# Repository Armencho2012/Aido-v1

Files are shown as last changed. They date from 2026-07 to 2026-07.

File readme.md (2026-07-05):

# AIDO — AI Study Assistant Robot

This repository contains the full AIDO project split across backend, frontend, firmware, tests, and 3D models.

## Repository structure

- `Aide server/` — backend voice API only, no browser UI.
- `Aide website/` — production-ready web application source and public assets.
- `Robot codes/` — MicroPython firmware and robot application logic.
- `Robot tests/` — hardware and software test scripts.
- `Robot 3d models/` — robot enclosure and part model files.

## Quick start

- Backend: run `Aide server` and configure `GROQ_API_KEY`.
- Frontend: build `Aide website` with `npm install` and `npm run build`.
- Robot firmware: deploy `Robot codes` to the Pico W device.
- Tests: run selected scripts from `Robot tests/harware` and `Robot tests/software`.

## Notes

- This repo is organized by subsystem, not by a single monolithic app.
- The backend service is API-only; the front-end and firmware are separate.
- Keep the `Aide website` folder clean from development-only artifacts.

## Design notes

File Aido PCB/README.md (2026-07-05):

# Aido PCB

This folder contains the printed circuit board design files for the AIDO project.

## Files

- `MyFirstController.kicad_sch` — schematic design
- `MyFirstController.kicad_pcb` — PCB layout
- `MyFirstController.kicad_prl` — PCB rules file
- `MyFirstController.kicad_pro` — PCB project file
- `ERC.rpt` — electrical rules check report
- `images/` — board diagrams and reference images

## Notes

- Use KiCad to open and edit the PCB design files.
- Keep generated artifacts out of source control if you want the repository clean.

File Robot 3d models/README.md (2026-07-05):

# Robot 3D Models

This folder contains the 3D model files for the AIDO robot design.

## Included files

- `Aido.stl` — main robot body for 3D printing or export
- `Aido.fbx` — main robot body for CAD, editing, or animation
- `back.stl` — secondary rear or cover part for printing
- `back.fbx` — secondary rear or cover part for CAD editing

## Usage

- Use `FBX` files for 3D modeling, editing, and visualization.
- Use `STL` files for 3D printing or slicing.
- Verify model units and orientation before exporting or printing.

## Notes

- Keep the `stl` and `fbx` files paired if you need both print-ready and editable versions.

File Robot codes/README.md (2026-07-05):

# Robot Codes

This folder contains the MicroPython firmware and application logic for the AIDO robot.

## Overview

The code is designed to run on the Pico W hardware and includes:

- `main.py` — primary application entry point
- `boot.py` — startup initialization and boot flow
- `config.py` — hardware pin assignments and configuration values
- `wifi.py` — WiFi connection manager
- `voice_client.py` — voice interaction client
- `tts_client.py` — text-to-speech client
- `mic.py`, `ssd1306.py`, `mpu6050.py`, `vl53l0x.py` — sensor and display drivers
- `flashcards.py`, `quiz.py`, `games.py`, `study_sync.py` — learning and interaction features

## Deployment

1. Copy the `Robot codes` files to the Pico W device storage.
2. Use Thonny, rshell, or a similar MicroPython tool.
3. Ensure `main.py` is present and the board boots from it.

## Notes

- Keep firmware code on the device and update only the required modules.
- Use the `config.py` file to verify pin assignments before hardware tests.

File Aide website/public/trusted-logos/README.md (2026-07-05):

# Trusted Logos

Current source of truth:

```bash
python3 scripts/fetch_trusted_logos.py
```

This downloads and writes:

- `logo-01.png`
- `logo-02.png`
- ...
- `logo-16.png`

If you want to split from a custom collage image instead, you can still use:

```bash
python3 scripts/extract_trusted_logos.py
```

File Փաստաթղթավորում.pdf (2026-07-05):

## ՎԱՆԱՁՈՐԻ ԹԻՎ 4 ՀԻՄՆԱԿԱՆ ԴՊՐՈՑԻ ԱՐՄԱԹ ՃԱՐՏԱՐԱԳԻՏԱԿԱՆ ԱՇԽԱՏԱՆՈՑ

# ՍԱՐՔԵՐԻ ԻՆՏԵԳՐՄԱՆ ՆԱԽԱԳԻԾ — ՏԵԽՆԻԿԱԿԱՆ ՓԱՍՏԱԹՈՒՂԹ

Խմբավար | Լուսինե Կոծինյան
Հեղինակ | Արմեն Ասլիկյան
Մասնակից | Մելս Մարտիրոսյան

Ի՞նչ է AIDO-ն

AIDO-ն խելացի ուսումնական օգնական է, այն միավորում է արհեստական բանականության մոդելները և ռոբոտաշինությունը՝ կրթական գործընթացն ավելի հետաքրքիր, արդյունավետ ու ինտերակտիվ դարձնելու համար: Այն հանդես է գալիս որպես անձնական թվային դասավանդող և օգնական: AIDO ն օգտագործում է ներկայիս լավագույն ԱԲ մոդելները հնարավորինս որակով պատասխան վերադարձնելու համար։

AIDO Study Assistant AI ռոբոտի հիմնական նպատակն է հեղափոխել ուսումնական գործընթացը՝ կապող օղակ հանդիսանալով առաջադեմ արհեստական բանականության և ֆիզիկական ռոբոտատեխնիկայի միջև: Ստեղծված լինելով որպես ինտերակտիվ և 24/7 հասանելի կրթական ընկեր՝ AIDO-ն նպատակ ունի հանրամատչելի դարձնել անհատականացված ուսուցումը՝ հարմարվելով յուրաքանչյուր սովորողի տեմպին ու ոճին: Ավտոմատացնելով ծավալուն ակադեմիական առաջադրանքները, ինչպիսիք են դասագրքերի վերլուծությունը, թիրախային թեստերի ստեղծումն ու բնական լեզվով ակնթարթային բացատրությունների տրամադրումը, ռոբոտը թեթևացնում է մտավոր ծանրաբեռնվածությունը և օպտիմալացնում սովորելու ժամանակը: Ի վերջո, AIDO-ն հանդես է գալիս ոչ թե պարզապես որպես պասիվ գործիք, այլ որպես նախաձեռնող կրթական գործընկեր, որը խթանում է նյութի խորը ընկալումը, բարելավում է գիտելիքների պահպանումը և բարձրորակ, տեխնոլոգիական մենթորությունը հասանելի է դարձնում

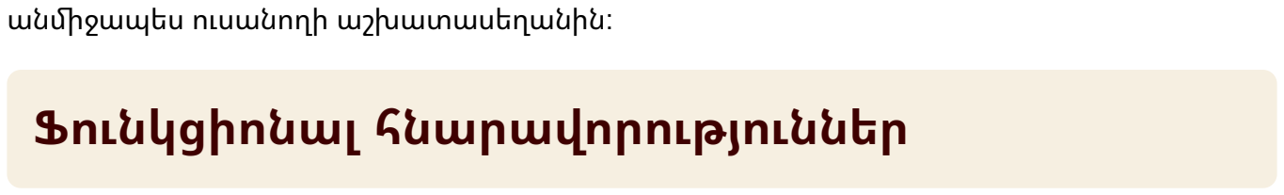
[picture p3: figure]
անմիջապես ուսանողի աշխատասեղանին:; Ֆունկցիոնալ հնարավորություններ

Ուսումնական նյութերի ավտոմատ ստեղծում․ Ռոբոտը ինքնաշխատ եղանակով գեներացնում է թեստեր (quizzes), հիշողության քարտեր (flashcards), վերլուծություններ (analyses) և ուսումնական քարտեզներ (study maps):

Խաղային էլեմենտներ (Gamification)․ Համակարգը ներառում է ներկառուցված կրթական խաղեր, որոնք ուսուցման գործընթացը դարձնում են ավելի հետաքրքիր:

Կարգավորումների բաժին (Settings)․ Օգտատերը կարող է հարմարեցնել ռոբոտի աշխատանքը և պարամետրերը հատուկ կառավարման վահանակի միջոցով:

Անիմացիաներ (Animations)․ Ռոբոտն ունի վիզուալ անիմացիաներ, որոնք ապահովում են կենդանի ու դինամիկ փոխազդեցություն սովորողի հետ:

Ինտերակտիվ երկխոսություն և դինամիկ թարմացում․ Օգտատերը կարող է խոսել ռոբոտի հետ, տալ հարցեր, իսկ ռոբոտը պատասխանում է դրանց: Զրույցի բովանդակության հիման վրա համակարգը ավտոմատ կերպով թարմացնում է թեստերը, ֆլեշ-քարտերը և մյուս ուսումնական նյութերը:

Վեբ տարբերակ (Web Version)․ Ռոբոտն ունի իր համապատասխան վեբ-կայքը, որն օգտատիրոջը հնարավորություն է տալիս կատարել ավելի ընդարձակ աշխատանքներ և

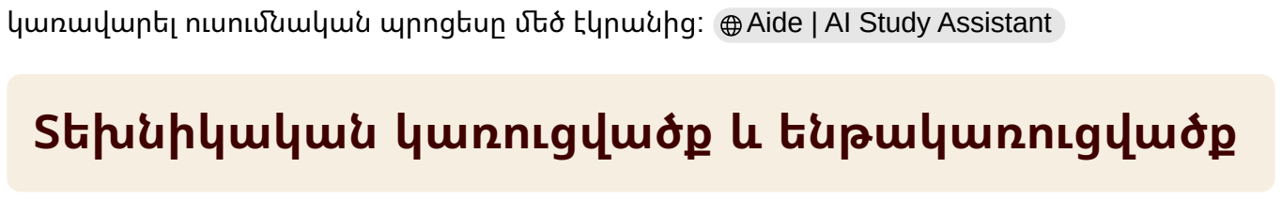
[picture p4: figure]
կառավարել ուսումնական պրոցեսը մեծ էկրանից:; Aide | AI Study Assistant; Տեխնիկական կառուցվածք և ենթակառուցվածք

Միկրոծրագրային ապահովում (Firmware)․ Ռոբոտի ներքին ծրագրային կոդը գրված է MicroPython լեզվով:

Վեբ տեխնոլոգիաներ (Web Stack)․ Նախագծի վեբ-կայքը մշակված է Node.js միջավայրում:

Սերվերային համակարգ (Hosting)․ Թե՛ ռոբոտի API սերվերները և թե՛ վեբ-կայքը հոսթինգ են անցնում Vercel հարթակում:

Տվյալների բազա (Database)․ Որպես կենտրոնական տվյալների բազա օգտագործվում է Supabase-ը, որը պահում է վեբ-կայքի և ռոբոտի ողջ տեղեկատվությունը:

Ձայնային հարցումների մշակման ալգորիթմ (Voice Processing Pipeline)

1. Ձայնագրում․ Ռոբոտը ձայնագրում է օգտատիրոջ հարցը և այն պահպանում որպես .wav ֆորմատի աուդիոֆայլ:
2. Աուդիոյի փոխանցում․ Ֆայլն ուղարկվում է Vercel-ում գտնվող սերվերներին:
3. Ձայնի տեքստայնացում (STT)․ Սերվերը ձայնային ֆայլը փոխանցում է Groq Cloud հարթակին, որտեղ whisper-large-v3-turbo մոդելի միջոցով աուդիոն վերածվում է տեքստի:
4. Պատասխանի գեներացում (LLM)․ Տեքստային հարցը մշակվում է llama-3.1-8b-instant մեծ լեզվական մոդելի կողմից, որն էլ պատրաստում է համապատասխան պատասխանը:
5. Տեքստի ձայնայնացում (TTS)․ Գեներացված տեքստային պատասխանը Google Translate TTS-ի միջոցով վերածվում է աուդիո ֆայլի:
6. Հետադարձ կապ․ Պատրաստի ձայնային պատասխանը, տեքստը և թարմացված ուսումնական տվյալները սերվերից վերադառնում են ռոբոտին:

Բաղադրիչ (Component) | Ֆունկցիա (Function) | Կապի ինտերֆեյս (Protocol)
Raspberry Pi Pico W | Կենտրոնական միկրոկոնտրոլեր (Ուղեղ) | — (WiFi 2.4GHz)
OLED Էկրան | Անիմացիաների և կարգավիճակի վիզուալիզացիա | I2C
MPU6050 | Իներցիալ տվիչ (Աքսելերոմետր / Գիրոսկոպ) | I2C
VL53L0X | Լազերային հեռաչափ (ToF տվիչ) | I2C
INMP441 | Բազմաուղղվածություն ունեցող թվային միկրոֆոն | I2S
MAX98357 | Թվային աուդիո ուժեղացուցիչ և DAC | I2S
MicroSD Module | Աուդիոֆայլերի և տվյալների լոկալ պահպանում | SPI
TTP223 | Սենսորային կոճակ (Touch sensor) | Digital GPIO
Բարձրախոս (Speaker) | Ձայնային պատասխանների նվագարկում | Անալոգ (MAX98357-ից)
3.7V LiPo + LiPo Charger/Booster (5V) | Սնուցման համակարգ | Power Lines

Այս բաժնում ներկայացված են AIDO ռոբոտի էլեկտրոնային կառուցվածքի գծագրերը, որոնք մշակվել են KiCad EDA ավտոմատացված նախագծման միջավայրում։

### Էլեկտրական Սխեմա (Circuit Schematic)

Սխեման ցույց է տալիս բոլոր բաղադրիչների (Raspberry Pi Pico W, տվիչներ, աուդիո մոդուլներ և սնուցման համակարգ) միջև առկա էլեկտրական կապերը, դիմադրությունները, կոնդենսատորները և ազդանշանային գծերը (I2C, I2S, SPI, GPIO)։

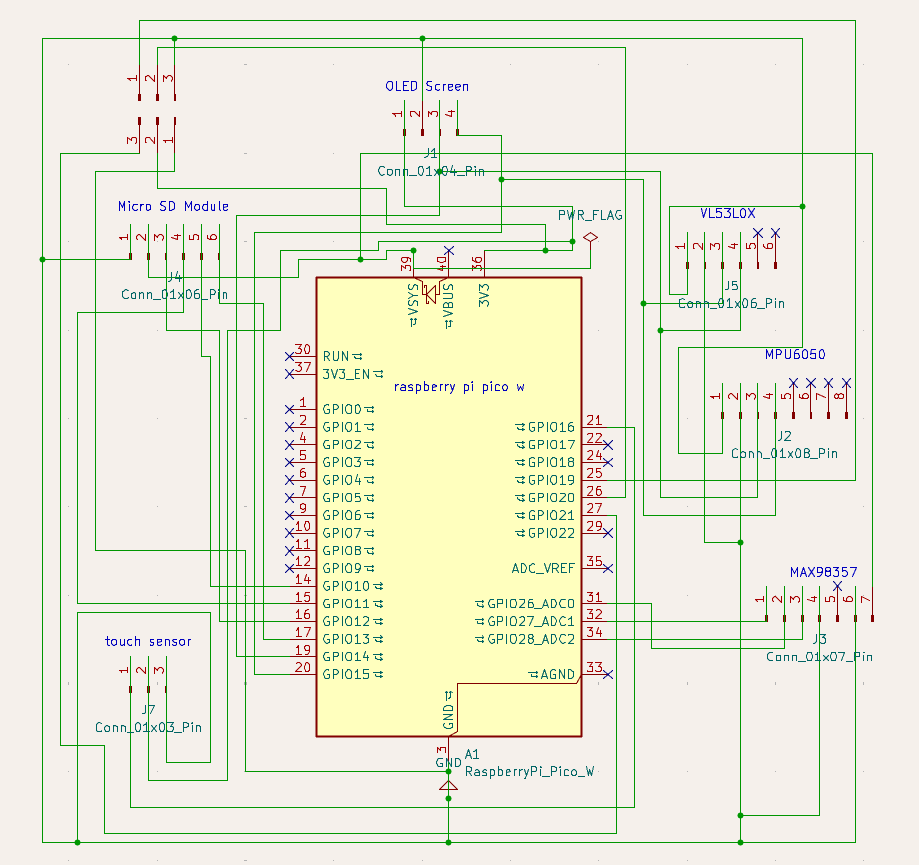
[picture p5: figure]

Տպասալիկի Նախագծում (PCB Layout)

Տպասալիկի (PCB) երկչափ (2D) կամ եռաչափ (3D) տեսքը, որտեղ արտացոլված է բաղադրիչների ֆիզիկական դասավորվածությունը, տպագիր ուղիների (traces) հաստությունն ու դիրքը, ինչպես նաև սնուցման և հողանցման (GND) շերտերը։

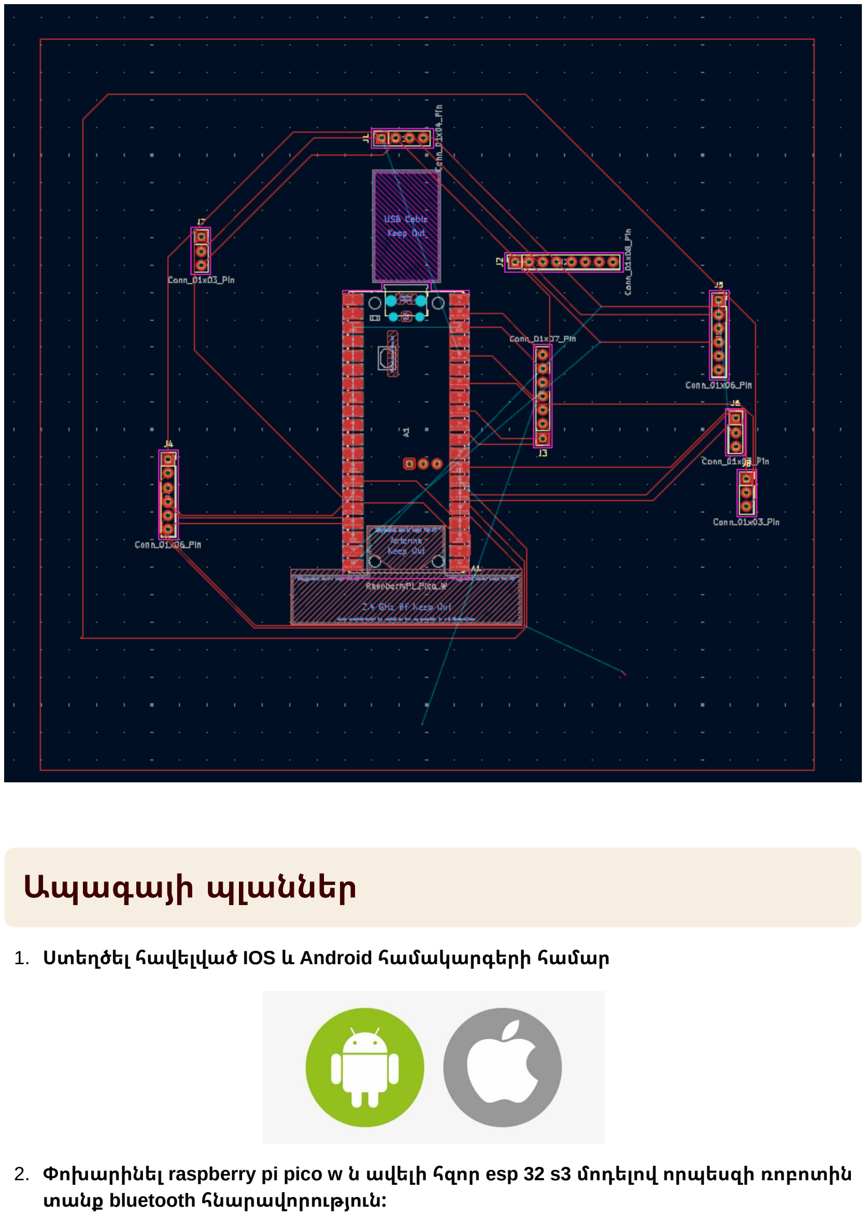
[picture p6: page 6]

## Ապագայի պլաններ

1. Ստեղծել հավելված IOS և Android համակարգերի համար
2. Փոխարինել raspberry pi pico w ն ավելի հզոր esp 32 s3 մոդելով որպեսզի ռոբոտին տանք bluetooth հնարավորություն։

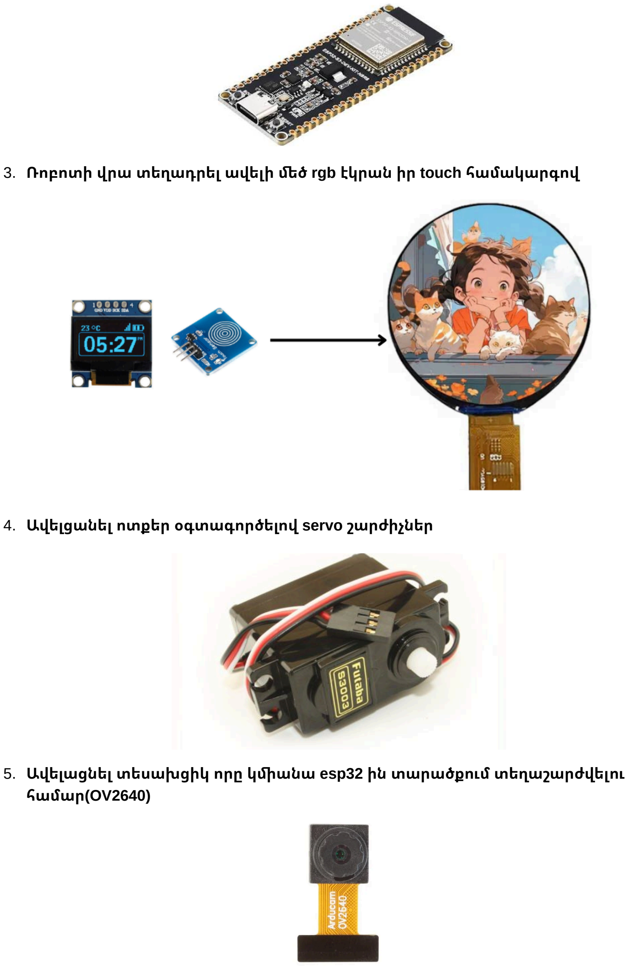
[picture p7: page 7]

3. Ռոբոտի վրա տեղադրել ավելի մեծ rgb էկրան իր touch համակարգով
4. Ավելցանել ոտքեր օգտագործելով servo շարժիչներ
5. Ավելացնել տեսախցիկ որը կմիանա esp32 ին տարածքում տեղաշարժվելու համար(OV2640)

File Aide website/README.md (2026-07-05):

# Aide website

This folder contains the production-ready frontend source for the AIDO project.

## Contents

- `src/` — main application source code
- `public/` — static assets and public files
- `package.json` — frontend dependency manifest and scripts
- `vite.config.ts` — Vite configuration for development and build
- `vercel.json` — deployment configuration for Vercel

## Notes

- This folder is for the website only; backend and firmware are in other folders.
- Keep only production source files here.

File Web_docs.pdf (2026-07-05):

# Aide Web Platform Documentation

# Aide — Web Platform Documentation

URL: https://myaide.vercel.app/

# English

## Overview

Aide is the web companion to the AIDO study-assistant robot. It lets a user upload notes, PDFs, or images and instantly turns them into structured study materials — summaries, quizzes, flashcards, knowledge maps, tutor chat, course plans, and podcasts. Where the physical AIDO robot provides a spoken, on-desk interface, the web platform is built for larger-screen use: reviewing generated materials in depth, managing a broader study workflow, and handling heavier uploads (full PDFs, multi-page notes, images) that aren’t practical to feed through the robot’s microphone alone.

## Purpose

The site exists to remove the manual work of turning raw study material into something usable for active recall and testing. Instead of a student manually writing flashcards or drafting practice questions, Aide automates that conversion — the same automation goal described for the AIDO robot itself, just accessed from a browser instead of the physical device.

## Core Features

Based on the platform’s stated capabilities:

Summaries — condenses uploaded notes, PDFs, or images into a shorter, structured overview of the material.
Quizzes — auto-generates test questions from the uploaded content, mirroring the Quiz module on the AIDO robot.
Flashcards — produces flashcard sets from the same material, mirroring the robot’s Flashcards module.
Knowledge Maps — builds a visual map of how concepts in the material relate to each other, corresponding to the robot’s Neural Map feature.
Tutor Chat — a conversational interface for asking questions about the uploaded material, similar in spirit to the robot’s voice Q&A pipeline but text-based and browser-native. Course Plans — organizes material into a structured study plan or sequence.
Podcasts — converts study material into audio-format content, likely useful for passive review (listening while commuting, etc.).

## Supported Input

Typed or pasted notes
PDF documents
Images (e.g. photographed textbook pages or handwritten notes)

## Relationship to the AIDO Robot

Aide (web) and AIDO (robot) share the same underlying study-material pipeline described in the AIDO project documentation:

Both rely on AI-generated quizzes, flashcards, analyses/summaries, and knowledge/neural maps.
Both are backed by the same infrastructure: Vercel for hosting and API routes, and Supabase as the central database storing study content for a given user.
The robot’s own voice pipeline (speech-to-text via Groq’s whisper-large-v3-turbo , response generation via llama-3.1-8b-instant , and text-to-speech via Google Translate TTS) produces material that syncs back to this same web platform, so study data generated by talking to the physical robot can, in principle, be reviewed later on the website’s larger screen — and vice versa.
The website is positioned as the place to do more “expansive” work and manage the overall study process, while the robot is positioned as the always-available, spoken, desk-side interface.

## Access

The platform is publicly accessible at https://myaide.vercel.app with no separate installation required — it runs directly in a web browser.

## Notes on This Documentation

This document was compiled from the site’s publicly available metadata (title, description, and keyword tags) together with details already established for the broader AIDO project (hardware, pipeline, and companion modules). The live site is a JavaScript-rendered application, so page-bypage interface details (exact screens, button layouts, account/sign-up flow, pricing if any) were not directly crawlable and are not included here. For a full interface walkthrough, a manual review of the live site or the project’s internal design docs would be needed to supplement this document.

# Հայերեն

## Ընդհանուր դիտարկում

Aide-ը AIDO ուսումնական օգնական ռոբոտի վեբ տարբերակն է։ Այն օգտատիրոջը թույլ է տալիս վերբեռնել գրառումներ, PDF ֆայլեր կամ նկարներ և ակնթարթորեն վերածել դրանք կառուցվածքային ուսումնական նյութերի՝ ամփոփումներ, թեստեր, հիշողության քարտեր, գիտելիքների քարտեզներ, դասավանդողի հետ չաթ, դասընթացների պլաններ և փոդքասթներ։ Այնտեղ, որտեղ ֆիզիկական AIDO ռոբոտն ապահովում է ձայնային, աշխատասեղանի վրայի ինտերֆեյս, վեբ հարթակը կառուցված է մեծ էկրանի համար օգտագործման նպատակով՝ գեներացված նյութերի մանրամասն վերանայում, ուսումնական ավելի ընդարձակ գործընթացի կառավարում և ծանր վերբեռնումների (ամբողջական PDF-եր, բազմաէջ գրառումներ, նկարներ) մշակում, որոնք գործնականում հնարավոր չէ փոխանցել միայն ռոբոտի միկրոֆոնի միջոցով։

## Նպատակ

Կայքի նպատակն է վերացնել հում ուսումնական նյութը ակտիվ կրկնության և ստուգման համար օգտագործելի ձևի վերածելու ձեռքով կատարվող աշխատանքը։ Փոխանակ ուսանողը ձեռքով գրի հիշողության քարտեր կամ կազմի փորձնական հարցեր, Aide-ն ավտոմատացնում է այդ փոխակերպումը՝ նույն ավտոմատացման նպատակով, ինչ նկարագրված է հենց AIDO ռոբոտի համար, պարզապես հասանելի դարձած բրաուզերի միջոցով՝ ֆիզիկական սարքի փոխարեն։

## Հիմնական հնարավորություններ

Հիմնված հարթակի հայտարարված հնարավորությունների վրա.

Ամփոփումներ — վերբեռնված գրառումները, PDF ֆայլերը կամ նկարները սեղմում է ավելի կարճ, կառուցվածքային ակնարկի մեջ։
Թեստեր (Quizzes) — ավտոմատ կերպով ստեղծում է թեստային հարցեր վերբեռնված նյութից՝ արտացոլելով AIDO ռոբոտի Quiz մոդուլը։
Հիշողության քարտեր (Flashcards) — ստեղծում է քարտերի հավաքածուներ նույն նյութից՝ արտացոլելով ռոբոտի Flashcards մոդուլը։
Գիտելիքների քարտեզներ (Knowledge Maps) — կառուցում է վիզուալ քարտեզ, թե ինչպես են նյութի հասկացությունները փոխկապակցված, ինչը համապատասխանում է ռոբոտի Neural Map հատկանիշին։
Դասավանդողի չաթ (Tutor Chat) — խոսակցական ինտերֆեյս՝ վերբեռնված նյութի վերաբերյալ հարցեր տալու համար, ոգով նման է ռոբոտի ձայնային հարց-պատասխան համակարգին, բայց տեքստային և բնիկ բրաուզերային։
Դասընթացների պլաններ (Course Plans) — կազմակերպում է նյութը կառուցվածքային ուսումնական պլանի կամ հաջորդականության մեջ։
Փոդքասթներ (Podcasts) — ուսումնական նյութը վերածում է աուդիո ֆորմատի բովանդակության, ինչը հավանաբար օգտակար է պասիվ վերանայման համար (օրինակ՝ լսել ճանապարհորդության ժամանակ)։

## Աջակցվող մուտքային ձևաչափեր

Մուտքագրված կամ տեղադրված գրառումներ
PDF փաստաթղթեր
Նկարներ (օրինակ՝ լուսանկարված դասագրքի էջեր կամ ձեռագիր գրառումներ)

## Կապը AIDO ռոբոտի հետ

Aide-ը (վեբ) և AIDO-ն (ռոբոտ) կիսում են նույն հիմքային ուսումնական նյութերի մշակման համակարգը, ինչպես նկարագրված է AIDO ծրագրի փաստաթղթերում.

Երկուսն էլ հենվում են AI-ի կողմից գեներացված թեստերի, հիշողության քարտերի, վերլուծությունների/ամփոփումների և գիտելիքի/նյարդային քարտեզների վրա։ Երկուսն էլ աշխատում են նույն ենթակառուցվածքի վրա՝ Vercel՝ հոսթինգի և API երթուղիների համար, և Supabase՝ որպես կենտրոնական տվյալների բազա, որը պահում է տվյալ օգտատիրոջ ուսումնական բովանդակությունը։
Ռոբոտի սեփական ձայնային համակարգը (խոսքի տեքստայնացում Groq-ի whisper-largev3-turbo մոդելով, պատասխանի գեներացում llama-3.1-8b-instant մոդելով, և տեքստի ձայնայնացում Google Translate TTS-ով) ստեղծում է նյութ, որը համաժամանակվում է այս նույն վեբ հարթակի հետ, այնպես որ ռոբոտի հետ խոսելով ստեղծված ուսումնական տվյալները սկզբունքորեն կարող են հետագայում վերանայվել կայքի ավելի մեծ էկրանից՝ և հակառակը։
Կայքը դիրքավորված է որպես ավելի «ընդարձակ» աշխատանք կատարելու և ընդհանուր ուսումնական գործընթացը կառավարելու տեղ, մինչդեռ ռոբոտը դիրքավորված է որպես միշտ հասանելի, ձայնային, աշխատասեղանի կողքի ինտերֆեյս։

## Հասանելիություն

Հարթակը հանրայնորեն հասանելի է https://myaide.vercel.app հասցեով՝ առանց առանձին տեղադրման կարիքի. այն աշխատում է անմիջապես վեբ բրաուզերում։

## Նշումներ այս փաստաթղթի վերաբերյալ

Այս փաստաթուղթը կազմվել է կայքի հանրայնորեն հասանելի մետատվյալների (վերնագիր, նկարագրություն և բանալի-բառեր) և AIDO ընդհանուր ծրագրի համար արդեն սահմանված մանրամասների (սարքավորում, համակարգ և ուղեկցող մոդուլներ) հիման վրա։ Կայքն ինքնին JavaScript-ով ցուցադրվող հավելված է, ուստի էջ առ էջ ինտերֆեյսի մանրամասները (ճշգրիտ էկրանները, կոճակների դասավորությունը, հաշվի ստեղծման/գրանցման հոսքը, գնային պլանները՝ եթե կան) ուղղակիորեն հասանելի չեղան և ընդգրկված չեն այստեղ։ Ինտերֆեյսի ամբողջական ուսումնասիրության համար անհրաժեշտ կլինի կայքի ձեռքով վերանայում կամ ծրագրի ներքին դիզայն-փաստաթղթերը՝ այս փաստաթուղթը լրացնելու համար։

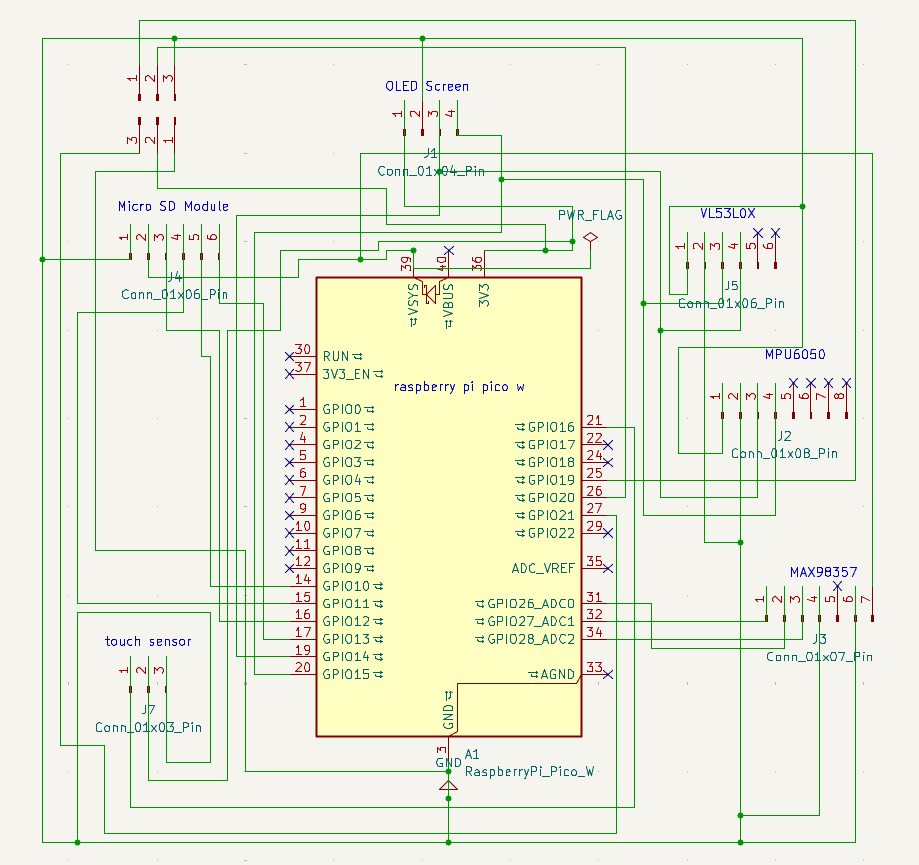
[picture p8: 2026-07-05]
Aido PCB/images/Schematic.png

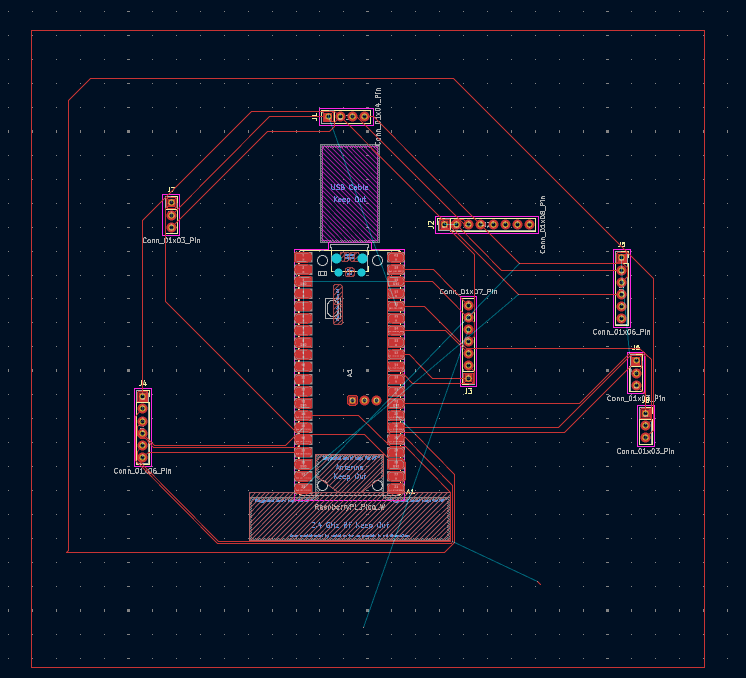
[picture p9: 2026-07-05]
Aido PCB/images/PCB.png

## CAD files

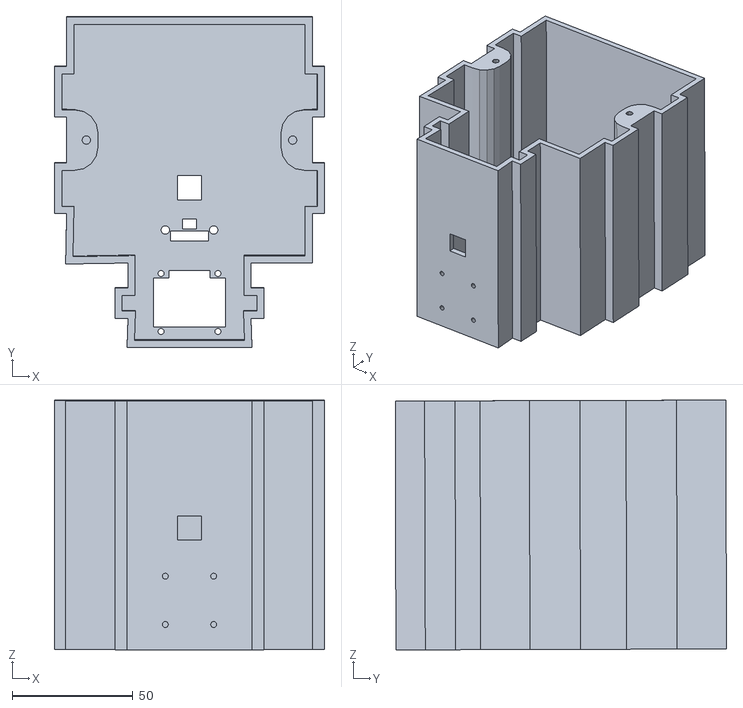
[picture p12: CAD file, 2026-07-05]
Robot 3d models/Aido.stl
111.7 x 137.0 x 103.4

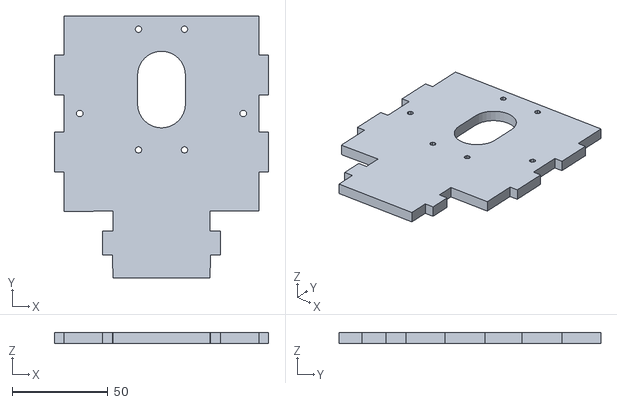
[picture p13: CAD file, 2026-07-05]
Robot 3d models/back.stl
111.7 x 136.7 x 6.00

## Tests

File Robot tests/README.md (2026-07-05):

# Robot Tests

This folder contains diagnostic and validation scripts for the AIDO project.

## Structure

- `harware/` — hardware-level tests for sensors, peripherals, and connectivity
- `software/` — software and integration tests for application behavior

## Hardware tests

- `1.connecting_to_pico_and_wifi.py` — WiFi connection test
- `2.touch_sensor.py` — touch input validation
- `3.oled_screen.py` — OLED display initialization and verification
- `4.vl53l0x_distance.py` — time-of-flight distance sensor test
- `5.microphone_test.py` — microphone/I2S audio capture test
- `6.mpu6050_sensor.py` — IMU initialization and readings
- `7.mounting_sd_card.py` — SD card mount and access test
- `8.speaker_and_MAX98357_test.py` — speaker and amplifier playback test
- `9.battery_testing.py` — battery voltage and percentage check

## Software tests

- `1.asking_questions.py` — question input and response flow
- `2.renewing_study_materials.py` — study material refresh process
- `3.quiz.py` — quiz engine test
- `4.flashcards.py` — flashcard workflow test
- `5.games.py` — game logic test
- `6.neural_map.py` — neural map visualization or logic test
- `7.getting_analyse.py` — analysis generation test
- `8.tts_roundtrip.py` — text-to-speech round-trip test
- `9.full_boot_integration_test.py` — full boot and system integration
- `10. free_memory_stress_test.py` — memory stress and stability test
- `11.watchdog.py` — watchdog timer validation

## Notes

- Run tests individually depending on the hardware and software component you want to verify.
- The folder name is intentionally `harware` to match the existing project structure.

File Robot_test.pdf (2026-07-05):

# AIDO-v1 Tests

# AIDO-v1 Tests

This | tests | folder contains diagnostic and integration scripts for the AIDO project. It is separated into two
subfolders:
hardware/ | — hardware-level tests for sensors, peripherals, and connectivity
software/ | — software-level tests for higher-level system features and modules

# English

## Overview

The | tests | folder is designed to help developers validate the AIDO hardware and software subsystems.

hardware/

1. | 1.connecting_to_pico_and_wifi.py | Connects the Pico board to WiFi using provided | SSID | and | PASSWORD .
Validates the WLAN connection flow.
2. | 2.touch_sensor.py | Tests the touch sensor input on GPIO pin 16. Uses single/double/three-tap detection and
| prints results.
3. | 3.oled_screen.py | Checks the I2C OLED display. Scans the I2C bus and attempts to initialize the OLED screen.
4. | 4.vl53l0x_distance.py | Tests the VL53L0X time-of-flight distance sensor. Reads distance data continuously for
| a short period.
5. | 5.microphone_test.py | Tests the microphone/I2S input path. Captures audio samples and computes a level
| meter.
6. | 6.mpu6050_sensor.py | Tests the MPU6050 inertial measurement unit (IMU). Scans I2C bus and initializes the
| accelerometer/gyro sensor.
7. | 7.mounting_sd_card.py | Verifies SD card SPI setup and mount flow. Ensures the board can access SD storage.
8. | 8.speaker_and_MAX98357_test.py | Verifies audio playback through the MAX98357 I2S speaker amplifier. Plays
welcome.wav | to confirm output.
9. | 9.battery_testing.py | Tests the battery voltage sensing via ADC. Prints raw ADC values and calculated
| battery voltage/percentage.

software/

1. | 1.asking_questions.py | Tests the voice question/response flow. Sends sample questions and validates speech
| recognition/response behavior.
2. | 2.renewing_study_materials.py | Recreates or refreshes study materials. Ensures flashcards, quiz content,
| analysis, and map files exist.
3. | 3.quiz.py | Tests the quiz engine module. Loads questions, displays options, and validates scoring.
4. | 4.flashcards.py | Tests the flashcards module. Loads content and verifies card browsing behavior.
5. | 5.games.py | Tests the games module and its mini-games. Includes Rock-Paper-Scissors, Pong, Reaction, and

Memory game flows.

6. | 6.neural_map.py | Tests the neural map visualization module. Renders and navigates the knowledge graph on
OLED.
7. | 7.getting_analyse.py | Tests the analysis module and study pack generation. Saves analysis, flashcards, quiz,
and map payloads.
8. | 8.tts_roundtrip.py | Tests WiFi and TTS server round-trip. Sends text to the TTS server and verifies a valid
WAV response.
9. | 9.full_boot_integration_test.py | A full integration test for system boot and module startup. Validates that the
system can initialize core subsystems.
10. | 10.free_memory_stress_test.py | Runs a memory/stress test across many subsystems. Tracks RAM usage during
OLED, WiFi, SD, microphone, and other initialization.
11. | 11.watchdog.py | Tests watchdog / crash recovery behavior. Confirms both fed and starved watchdog
operation.

# Հայերեն

## Ընդհանուր դիտարկում

tests թղթապանակը նախատեսված է AIDO սարքավորման և ծրագրային ապահովման ենթակարգերի ստուգման համար։

hardware/

1. | 1.connecting_to_pico_and_wifi.py | Միացնում է Pico տախտակը WiFi-ին տրված | SSID | և | PASSWORD
օգտագործելով։ Ստուգում է WLAN կապի հոսքը։
2. | 2.touch_sensor.py | Ստուգում է հպման տվիչի մուտքը GPIO 16 փինի վրա։ Օգտագործում է մեկ/երկու/երեք
հպման հայտնաբերում և տպում է արդյունքները։
3. | 3.oled_screen.py | Ստուգում է I2C OLED էկրանը։ Սկանում է I2C ավտոբուսը և փորձում է
նախապատրաստել OLED էկրանը։
4. | 4.vl53l0x_distance.py | Ստուգում է VL53L0X ժամանակի-թռիչքի (ToF) հեռավորության տվիչը։ Կարճ
ժամանակահատվածում շարունակաբար կարդում է հեռավորության տվյալները։
5. | 5.microphone_test.py | Ստուգում է միկրոֆոնի / I2S մուտքի ուղին։ Գրանցում է ձայնային նմուշներ և
հաշվարկում մակարդակաչափը։
6. | 6.mpu6050_sensor.py | Ստուգում է MPU6050 իներցիալ չափման միավորը (IMU)։ Սկանում է I2C ավտոբուսը
և նախապատրաստում է արագացուցիչը/գիրոսկոպը։
7. | 7.mounting_sd_card.py | Վավերացնում է SD քարտի SPI կարգավորումը և mount հոսքը։ Ապահովում է, որ
տախտակը կարող է մուտք գործել SD պահեստ։
8. | 8.speaker_and_MAX98357_test.py | Ստուգում է աուդիո նվագարկումը MAX98357 I2S բարձրախոսի
ուժեղացուցչի միջոցով։ Նվագարկում է | welcome.wav -ը՝ ելքը հաստատելու համար։
9. | 9.battery_testing.py | Ստուգում է մարտկոցի լարման զգայունությունը ADC-ի միջոցով։ Տպում է հում ADC
արժեքները և հաշվարկված մարտկոցի լարումը/տոկոսը։

software/

1. | 1.asking_questions.py | Ստուգում է ձայնային հարց/պատասխան հոսքը։ Ուղարկում է օրինակելի հարցեր
և վավերացնում ձայնի ճանաչման/պատասխանի վարքագիծը։

2. | 2.renewing_study_materials.py | Վերստեղծում կամ թարմացնում է ուսումնական նյութերը։ Ապահովում է,
որ flashcards, quiz բովանդակությունը, վերլուծությունը և քարտեզի ֆայլերը գոյություն ունեն։
3. | 3.quiz.py | Ստուգում է quiz շարժիչ մոդուլը։ Բեռնում է հարցերը, ցուցադրում տարբերակները և
վավերացնում գնահատումը։
4. | 4.flashcards.py | Ստուգում է flashcards մոդուլը։ Բեռնում է բովանդակությունը և վավերացնում քարտերի
դիտարկման վարքագիծը։
5. | 5.games.py | Ստուգում է խաղերի մոդուլը և դրա մինի-խաղերը։ Ներառում է Քար-Թուղթ-Մկրատ, Պինգ-
պոնգ, Ռեակցիա և Հիշողություն խաղերի հոսքերը։
6. | 6.neural_map.py | Ստուգում է նյարդային քարտեզի վիզուալացման մոդուլը։ Ներկայացնում և նավարկում
է գիտելիքների գրաֆը OLED-ի վրա։
7. | 7.getting_analyse.py | Ստուգում է վերլուծության մոդուլը և ուսումնական փաթեթի ստեղծումը։
Պահպանում է analysis, flashcards, quiz և map տվյալները։
8. | 8.tts_roundtrip.py | Ստուգում է WiFi և TTS սերվերի երթուղին։ Ուղարկում է տեքստ TTS սերվերին և
ստուգում ճշգրիտ WAV պատասխանը։
9. | 9.full_boot_integration_test.py | Ամբողջական ինտեգրման թեստ համակարգի բեռնման և մոդուլների
մեկնարկի համար։ Վավերացնում է, որ համակարգը կարող է նախապատրաստել հիմնական ենթահամակարգերը։
10. | 10.free_memory_stress_test.py | Կատարում է հիշողության/սթրես թեստ բազմաթիվ ենթահամակարգերի
վրա։ Հետևում է RAM-ի օգտագործմանը OLED, WiFi, SD, միկրոֆոնի և այլ նախապատրաստումների ընթացքում։
11. | 11.watchdog.py | Ստուգում է watchdog-ի / վթարից վերականգնման վարքագիծը։ Հաստատում է ինչպես
սնուցվող, այնպես էլ քաղցած WDT գործողությունը։

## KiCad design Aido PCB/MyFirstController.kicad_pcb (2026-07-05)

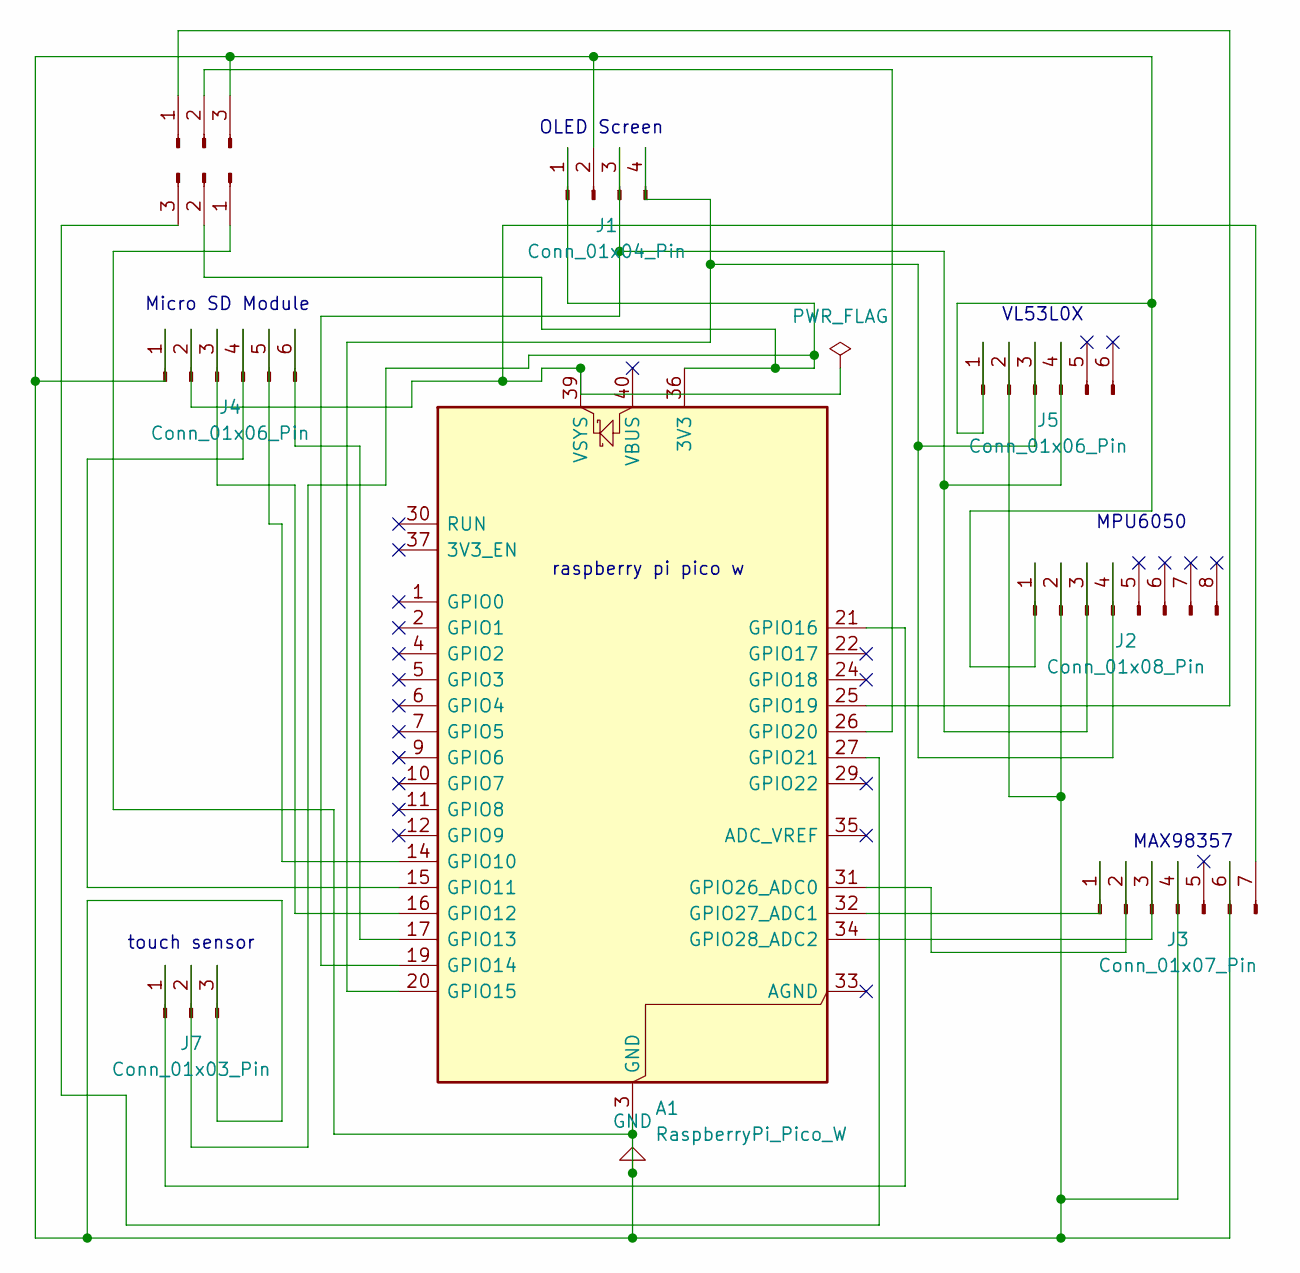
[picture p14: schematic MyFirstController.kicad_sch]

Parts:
A1: RaspberryPi_Pico_W; RaspberryPi_Pico_W_SMD_HandSolder
J1: Conn_01x04_Pin; PinSocket_1x04_P2.54mm_Vertical
J2: Conn_01x08_Pin; PinSocket_1x08_P2.54mm_Vertical
J3: Conn_01x07_Pin; PinSocket_1x07_P2.54mm_Vertical
J4, J5: Conn_01x06_Pin; PinSocket_1x06_P2.54mm_Vertical
J6, J7, J8: Conn_01x03_Pin; PinSocket_1x03_P2.54mm_Vertical

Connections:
GND: A1.3 (GND), A1.8 (GND), A1.13 (GND), A1.18 (GND), A1.23 (GND), A1.28 (GND), A1.38 (GND), J1.2, J2.1, J2.2, J3.4, J3.6, J4.1, J5.1, J5.2, J6.3, J7.3, J8.1
unnamed: A1.36 (3V3), J1.1, J7.2, J8.2
unnamed: A1.14 (GPIO10), J4.5
unnamed: A1.15 (GPIO11), J4.4
unnamed: A1.16 (GPIO12), J4.3
unnamed: A1.17 (GPIO13), J4.6
unnamed: A1.19 (GPIO14), J1.3, J2.3, J5.4
unnamed: A1.20 (GPIO15), J1.4, J2.4, J5.3
unnamed: A1.21 (GPIO16), J7.1
unnamed: A1.25 (GPIO19), J6.1
unnamed: A1.26 (GPIO20), J6.2
unnamed: A1.27 (GPIO21), J8.3
unnamed: A1.31 (GPIO26_ADC0), J3.2
unnamed: A1.32 (GPIO27_ADC1), J3.1
unnamed: A1.34 (GPIO28_ADC2), J3.3
unnamed: A1.39 (VSYS), J3.7, J4.2

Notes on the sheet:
raspberry pi pico w
MPU6050
Micro SD Module
MAX98357
touch sensor
OLED Screen
VL53L0X

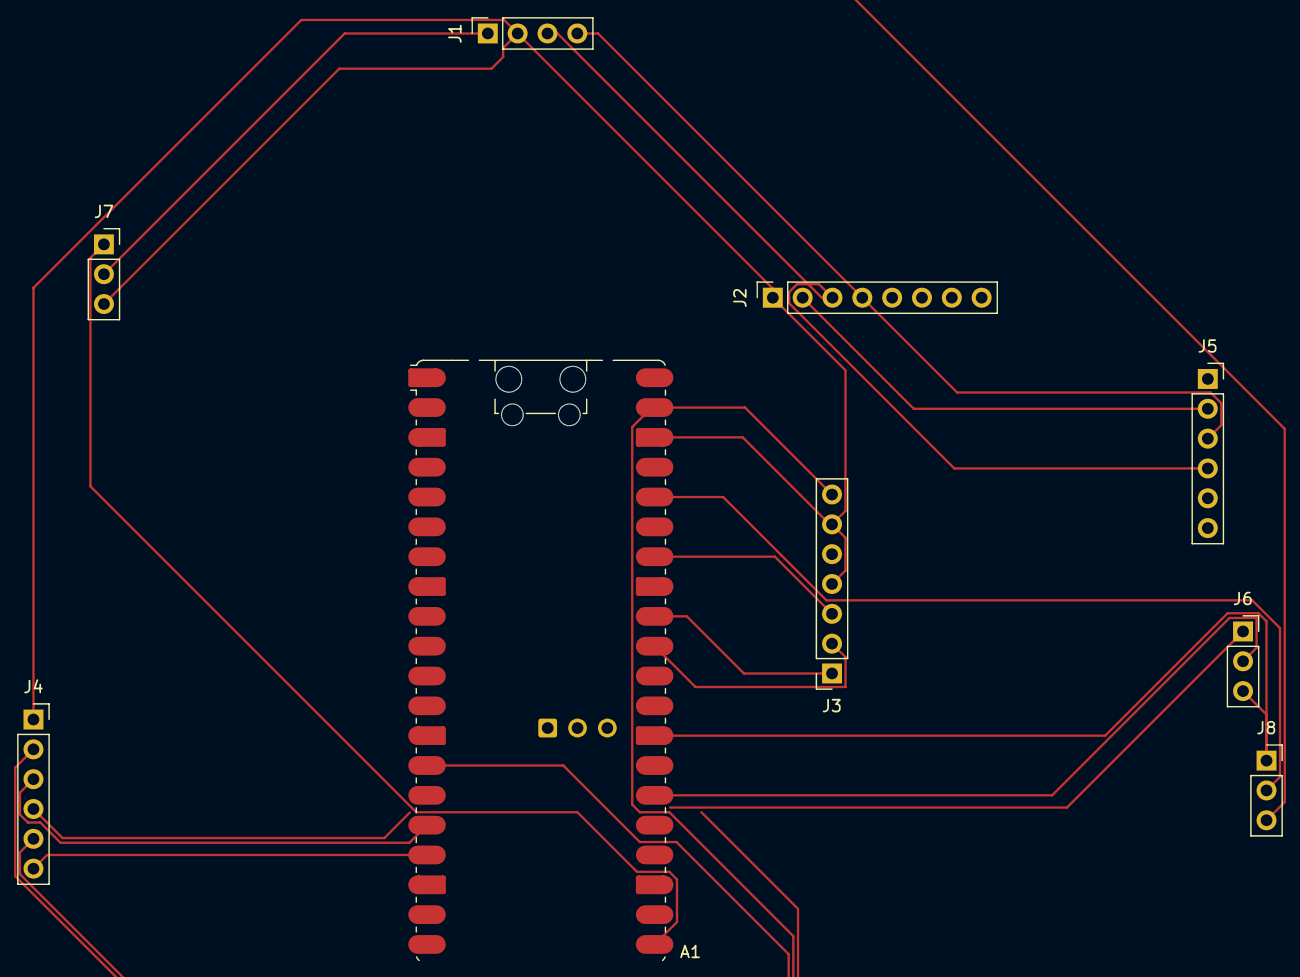
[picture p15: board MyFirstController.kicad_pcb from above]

Board: 2 copper layers, 9 parts (0 on the bottom side), 16 nets.

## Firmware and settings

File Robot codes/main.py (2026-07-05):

import machine
import time
import gc
import os
import sys
from config import (
    I2C_SDA_PIN, I2C_SCL_PIN, I2C_FREQ,
    TOUCH_PIN, LED_PIN, OLED_WIDTH, OLED_HEIGHT, OLED_ADDR,
    FRAME_DELAY_MS, STATE_INPUT_LOCK_MS,
    STATE_BOOT, STATE_FACE, STATE_MENU, STATE_ACTION,
    STATE_FLASHCARD, STATE_QUIZ, STATE_TALK,
    STATE_SETTINGS, STATE_NEURAL, STATE_GAMES, STATE_ANALYSE,
    EXPR_NEUTRAL, EXPR_HAPPY, EXPR_SAD, EXPR_ANGRY,
    EXPR_SURPRISE, EXPR_SLEEPY, EXPR_LOVE, EXPR_THINK,
    EXPR_BLINK, EXPR_WINK, EXPR_TALK,
    MPU_EYE_GAIN,
    SD_WELCOME_WAV,
    VOICE_PUSH_TO_TALK,
)
print("\n" + "=" * 40)
print("  AIDO OS v3.0 — Booting...")
print("=" * 40)
i2c = machine.SoftI2C(
    sda=machine.Pin(I2C_SDA_PIN),
    scl=machine.Pin(I2C_SCL_PIN),
    freq=I2C_FREQ
)
print("[I2C] Scanning bus...")
devices = i2c.scan()
print("[I2C] Found {} device(s): {}".format(
    len(devices),
    ["0x{:02X}".format(d) for d in devices]
))
from lib.ssd1306 import SSD1306_I2C
oled = SSD1306_I2C(OLED_WIDTH, OLED_HEIGHT, i2c, addr=OLED_ADDR)
oled.contrast(255)
print("[OLED] {}x{} initialized".format(OLED_WIDTH, OLED_HEIGHT))
touch_pin = machine.Pin(TOUCH_PIN, machine.Pin.IN, machine.Pin.PULL_DOWN)
try:
    from touch import (
        TouchEngine,
        GESTURE_NAMES,
        GESTURE_TAP,
        GESTURE_DOUBLE_TAP,
        GESTURE_TRIPLE_TAP,
    )
except ImportError:
    print("[TOUCH] touch.py missing; using built-in touch reader")
    try:
        import config as _touch_config
    except ImportError:
        _touch_config = None
    def _touch_cfg(name, default):
        if _touch_config is None:
            return default
        return getattr(_touch_config, name, default)
    _TOUCH_DEBOUNCE_MS = _touch_cfg("DEBOUNCE_MS", 18)
    _TOUCH_DOUBLE_TAP_MS = _touch_cfg("DOUBLE_TAP_MS", 340)
    _TOUCH_TRIPLE_TAP_MS = _touch_cfg("TRIPLE_TAP_MS", 260)
    _TOUCH_MODE = _touch_cfg("TOUCH_MODE", "auto")
    _TOUCH_IDLE_LEARN_MS = _touch_cfg("TOUCH_IDLE_LEARN_MS", 700)
    _TOUCH_TOGGLE_LEARN_MS = _touch_cfg("TOUCH_TOGGLE_LEARN_MS", 220)
    GESTURE_NONE       = 0
    GESTURE_TAP        = 1
    GESTURE_DOUBLE_TAP = 2
    GESTURE_TRIPLE_TAP = 3
    GESTURE_NAMES = {
        0: "NONE",
        1: "TAP",
        2: "DOUBLE",
        3: "BACK",
    }
    _TOUCH_MODE_AUTO = "auto"
    _TOUCH_MODE_MOMENTARY = "momentary"
    _TOUCH_MODE_TOGGLE = "toggle"
    class TouchEngine:
        def __init__(self, pin):
            self.pin = pin
            self._configured_mode = self._normalize_mode(_TOUCH_MODE)
            self._mode = None if self._configured_mode == _TOUCH_MODE_AUTO else self._configured_mode
            self._idle = self._learn_idle()
            self._raw = int(self.pin.value())
            self._stable = self._raw
            now = time.ticks_ms()
            self._last_raw_change = now
            self._active_since = now if self._stable != self._idle else 0
            self._clear_taps()
            print("[TOUCH] Built-in idle={}".format(self._idle))
        def _normalize_mode(self, mode):
            mode = str(mode).lower()
            if mode in ("toggle", "latched", "latch", "edge"):
                return _TOUCH_MODE_TOGGLE
            if mode in ("momentary", "press", "button"):
                return _TOUCH_MODE_MOMENTARY
            return _TOUCH_MODE_AUTO
        def _learn_idle(self):
            zeroes = 0
            ones = 0
            start = time.ticks_ms()
            while time.ticks_diff(time.ticks_ms(), start) < _TOUCH_IDLE_LEARN_MS:
                if int(self.pin.value()):
                    ones += 1
                else:
                    zeroes += 1
                time.sleep_ms(5)
            return 1 if ones > zeroes else 0
        def _clear_taps(self):
            self._tap_count = 0
            self._tap_deadline = None
        def _set_auto_mode(self, mode):
            if self._configured_mode != _TOUCH_MODE_AUTO:
                return
            if self._mode != mode:
                self._mode = mode
                print("[TOUCH] Auto mode -> {}".format(mode))
        def reset(self):
            now = time.ticks_ms()
            self._raw = int(self.pin.value())
            self._stable = self._raw
            self._last_raw_change = now
            self._active_since = now if self._stable != self._idle else 0
            self._clear_taps()
        def cancel_pending(self):
            self._clear_taps()
            self._active_since = time.ticks_ms() if self._stable != self._idle else 0
        def update(self):
            now = time.ticks_ms()
            raw = int(self.pin.value())
            if raw != self._raw:
                self._raw = raw
                self._last_raw_change = now
            if raw != self._stable:
                if time.ticks_diff(now, self._last_raw_change) >= _TOUCH_DEBOUNCE_MS:
                    self._stable = raw
                    gesture = self._handle_edge(now)
                    if gesture:
                        return gesture
            if (
                self._mode is None
                and self._stable != self._idle
                and self._active_since
                and time.ticks_diff(now, self._active_since) >= _TOUCH_TOGGLE_LEARN_MS
            ):
                self._set_auto_mode(_TOUCH_MODE_TOGGLE)
            return self._finish_waiting_gesture(now)
        def _handle_edge(self, now):
            active = self._stable != self._idle
            if self._mode == _TOUCH_MODE_TOGGLE:
                return self._count_tap(now)
            if active:
                self._active_since = now
                return self._count_tap(now)
            self._active_since = 0
            if self._mode is None:
                self._set_auto_mode(_TOUCH_MODE_MOMENTARY)
            return GESTURE_NONE
        def _count_tap(self, now):
            if self._tap_deadline is not None and time.ticks_diff(now, self._tap_deadline) > 0:
                self._clear_taps()
            self._tap_count += 1
            if self._tap_count >= 3:
                self._clear_taps()
                return GESTURE_TRIPLE_TAP
            wait_ms = _TOUCH_DOUBLE_TAP_MS if self._tap_count == 1 else _TOUCH_TRIPLE_TAP_MS
            self._tap_deadline = time.ticks_add(now, wait_ms)
            return GESTURE_NONE
        def _finish_waiting_gesture(self, now):
            if self._tap_deadline is None:
                return GESTURE_NONE
            if time.ticks_diff(now, self._tap_deadline) < 0:
                return GESTURE_NONE
            gesture = GESTURE_TAP if self._tap_count == 1 else GESTURE_DOUBLE_TAP
            self._clear_taps()
            return gesture
        @property
        def is_active(self):
            if self._mode == _TOUCH_MODE_TOGGLE:
                return bool(self._tap_count)
            return bool(self._tap_count or self._stable != self._idle)
        @property
        def blocks_voice_poll(self):
            return self.is_active
        @property
        def is_pressed(self):
            return self._stable != self._idle
touch = TouchEngine(touch_pin)
print("[TOUCH] GPIO{} ready".format(TOUCH_PIN))
led = machine.Pin(LED_PIN, machine.Pin.OUT)
led.value(0)
print("[LED] GPIO{} ready".format(LED_PIN))
from mpu6050 import MPU6050, VirtualMPU
try:
    mpu = MPU6050(i2c)
    if not mpu.available:
        raise OSError("MPU not responding")
except Exception:
    print("[MPU] Using virtual fallback")
    mpu = VirtualMPU()
from face import FaceEngine
from menu import MenuSystem
from status import StatusBar
from boot_anim import BootAnimation
from audio import AudioEngine
from car_anim import play as play_car_transition
from mic import VoiceAssistant
from tof_behavior import ToFKissController
try:
    import study_sync as _study_sync
except Exception as e:
    print("[STUDY] Module unavailable:", e)
    _study_sync = None
from storage_paths import (
    runtime_flashcards_path,
    runtime_quiz_path,
    runtime_welcome_path,
    sd_available,
)
def file_exists(path):
    if _study_sync and hasattr(_study_sync, "file_exists"):
        return _study_sync.file_exists(path)
    try:
        os.stat(path)
        return True
    except OSError:
        return False
def load_analysis():
    if _study_sync and hasattr(_study_sync, "load_analysis"):
        return _study_sync.load_analysis()
    return None
def load_map():
    if _study_sync and hasattr(_study_sync, "load_map"):
        return _study_sync.load_map()
    return None
def ensure_study_files():
    if _study_sync and hasattr(_study_sync, "ensure_study_files"):
        return _study_sync.ensure_study_files()
    return False
face = FaceEngine()
menu = MenuSystem()
status = StatusBar(position="top")
boot_anim = BootAnimation()
audio = AudioEngine()
tof = ToFKissController(i2c)
voice = VoiceAssistant(oled, audio, face, touch_pin)
flashcards = None
quiz = None
neural = None
games = None
wifi = None
analysis_data = None
def _release_feature_memory(reason=""):
    """Drop optional app state before voice/TLS work needs a large heap."""
    global flashcards, quiz, neural, games, wifi, analysis_data
    before = gc.mem_free()
    flashcards = None
    quiz = None
    neural = None
    games = None
    wifi = None
    analysis_data = None
    try:
        modules = sys.modules
        for name in ("flashcards", "quiz", "neural", "games", "wifi"):
            try:
                del modules[name]
            except Exception:
                pass
    except Exception:
        pass
    gc.collect()
    after = gc.mem_free()
    if after > before + 1024:
        label = " for " + reason if reason else ""
        print("[OS] Freed RAM{}: {} -> {} bytes".format(label, before, after))
def _cleanup_sd_runtime_files():
    runtime_files = (
        "voice_in.wav",
        "voice_reply.wav",
        "voice_reply.wav.tmp",
        "welcome.wav.tmp",
        "voice_confirm.wav",
        "voice_yesno.wav",
    )
    for name in runtime_files:
        try:
            os.remove(name)
            print("[FS] Removed", name)
        except Exception:
            pass
    if sd_available():
        for name in runtime_files:
            path = "/sd/" + name
            try:
                os.remove(path)
                print("[SD] Removed", name)
            except OSError:
                pass
            except Exception as e:
                print("[SD] Skip {}: {}".format(name, e))
print("[OS] Core systems loaded")
print("[OS] Free RAM: {} bytes".format(gc.mem_free()))
def _existing_file(*paths):
    """Return the first readable file path from the given candidates."""
    for path in paths:
        try:
            os.stat(path)
            return path
        except OSError:
            pass
    return paths[0] if paths else None
def _play_wav_without_mic(path):
    """Play speaker audio while the mic RX engine is paused."""
    try:
        voice.suspend_input()
    except Exception:
        pass
    try:
        return audio.play_wav(path)
    finally:
        try:
            audio.shutdown()
            gc.collect()
            print("[AUDIO] Released I2S after playback; RAM:", gc.mem_free())
        except Exception:
            pass
        try:
            voice.resume_input()
        except Exception:
            pass
def _welcome_wav_supported(meta):
    """Return True only for WAVs the speaker path can actually play."""
    return bool(
        meta
        and meta.get("format") == 1
        and meta.get("rate") == 22050
        and meta.get("channels") == 1
        and meta.get("bits") == 16
        and meta.get("data_size", 0) > 4096
        and not meta.get("stream_size")
    )
def _welcome_path_candidates():
    """Try local first, then SD/runtime welcome if the SD card has one."""
    runtime_path = runtime_welcome_path()
    paths = ("welcome.wav", runtime_path)
    result = []
    for path in paths:
        if path not in result:
            result.append(path)
    return result
def _play_startup_welcome_voice():
    """Play cached welcome.wav, refreshing it first when the cache is unusable."""
    from config import PLAY_WELCOME_VOICE, REFRESH_WELCOME_WAV
    from tts_client import fetch_and_save_welcome
    if not PLAY_WELCOME_VOICE:
        print("[OS] Welcome voice disabled")
        return False
    welcome_path = None
    meta = None
    for candidate in _welcome_path_candidates():
        candidate_meta = audio.inspect_wav(candidate)
        if _welcome_wav_supported(candidate_meta):
            welcome_path = candidate
            meta = candidate_meta
            break
        if candidate_meta:
            print(
                "[OS] Skipping unsupported welcome WAV {}: fmt={}, {}Hz, {}bit, {}ch, data={}".format(
                    candidate,
                    candidate_meta.get("format", "?"),
                    candidate_meta.get("rate", "?"),
                    candidate_meta.get("bits", "?"),
                    candidate_meta.get("channels", "?"),
                    candidate_meta.get("data_size", "?"),
                )
            )
    if not meta and REFRESH_WELCOME_WAV:
        print("[OS] Cached welcome missing/invalid; fetching voice...")
        welcome_path = runtime_welcome_path()
        if fetch_and_save_welcome(welcome_path, lang="en"):
            meta = audio.inspect_wav(welcome_path)
    if not _welcome_wav_supported(meta):
        return False
    print("[OS] Playing welcome voice")
    if _play_wav_without_mic(welcome_path):
        return True
    if REFRESH_WELCOME_WAV:
        print("[OS] Welcome playback failed; fetching a fresh copy...")
        if fetch_and_save_welcome("welcome.wav", lang="en"):
            return _play_wav_without_mic("welcome.wav")
    return False
current_state = STATE_BOOT
prev_state = STATE_BOOT
state_stack = []
expression_timer = 0
expression_auto = True
frame_count = 0
last_frame_time = time.ticks_ms()
fps = 0
fps_counter = 0
fps_timer = last_frame_time
input_lock_until = 0
voice_poll_block_until = 0
def _lock_input(duration_ms=STATE_INPUT_LOCK_MS):
    global input_lock_until
    input_lock_until = time.ticks_add(time.ticks_ms(), duration_ms)
def _input_locked():
    return time.ticks_diff(input_lock_until, time.ticks_ms()) > 0
def _block_voice_poll(duration_ms=800):
    global voice_poll_block_until
    voice_poll_block_until = time.ticks_add(time.ticks_ms(), duration_ms)
def _voice_poll_blocked():
    return time.ticks_diff(voice_poll_block_until, time.ticks_ms()) > 0
def _reset_touch_for_state_change():
    touch.reset()
    _lock_input()
def change_state(new_state):
    """Transition to a new OS state with stack tracking."""
    global current_state, prev_state
    if new_state == current_state:
        return
    state_stack.append(current_state)
    if len(state_stack) > 10:
        state_stack.pop(0)
    prev_state = current_state
    current_state = new_state
    print("[OS] State: {} -> {}".format(prev_state, current_state))
    _reset_touch_for_state_change()
    _on_state_enter(new_state)
def go_back():
    """Navigate back one level in the state stack."""
    global current_state, prev_state
    if state_stack:
        prev_state = current_state
        current_state = state_stack.pop()
        print("[OS] Back to state {}".format(current_state))
        _reset_touch_for_state_change()
        _on_state_enter(current_state)
    else:
        if current_state != STATE_FACE:
            prev_state = current_state
            current_state = STATE_FACE
            print("[OS] Back to face (stack empty)")
            _reset_touch_for_state_change()
            _on_state_enter(current_state)
def _on_state_enter(state):
    """Called when entering a new state — initialize subsystems."""
    global flashcards, quiz, neural, games, wifi, analysis_data
    gc.collect()
    if state == STATE_MENU:
        menu.open()
        face.set_expression(EXPR_NEUTRAL)
    elif state == STATE_FACE:
        _release_feature_memory("face")
        face.set_expression(EXPR_NEUTRAL)
        face.set_talk(False)
        voice.flush_mic()
    elif state == STATE_FLASHCARD:
        if flashcards is None:
            from flashcards import FlashcardEngine
            flashcards = FlashcardEngine()
            flashcards.on_expression = _set_temp_expression
        flashcards_path = runtime_flashcards_path()
        if file_exists(flashcards_path):
            flashcards.load_deck(flashcards_path)
        flashcards.reset_session()
        face.set_expression(EXPR_THINK)
    elif state == STATE_QUIZ:
        if quiz is None:
            from quiz import QuizEngine
            quiz = QuizEngine()
            quiz.on_expression = _set_temp_expression
        quiz_path = runtime_quiz_path()
        if file_exists(quiz_path):
            quiz.load_questions(quiz_path)
        quiz.start()
    elif state == STATE_NEURAL:
        if neural is None:
            from neural import NeuralMapEngine
            neural = NeuralMapEngine()
        neural.load_map(load_map())
    elif state == STATE_GAMES:
        if games is None:
            from games import GamesEngine
            games = GamesEngine(audio.play_fx)
    elif state == STATE_TALK:
        face.set_expression(EXPR_TALK)
        face.set_talk(True)
    elif state == STATE_SETTINGS:
        if wifi is None:
            from wifi import WiFiManager
            wifi = WiFiManager()
    elif state == STATE_ANALYSE:
        analysis_data = load_analysis()
    print("[OS] Free RAM: {} bytes".format(gc.mem_free()))
def _set_temp_expression(expr, duration_ms=1500):
    """Set a temporary expression that auto-resets."""
    global expression_timer
    face.set_expression(expr)
    expression_timer = time.ticks_add(time.ticks_ms(), duration_ms)
def _transition_to_state(new_state):
    """Play the short car transition before changing screens."""
    play_car_transition(oled)
    change_state(new_state)
def handle_input(gesture):
    """Route touch gestures to the current state handler."""
    global current_state
    if gesture == 0:
        return
    print("[TOUCH] {}".format(GESTURE_NAMES.get(gesture, gesture)))
    if gesture == GESTURE_TAP:
        audio.play_fx("tap")
    elif gesture == GESTURE_DOUBLE_TAP:
        audio.play_fx("double_tap")
    elif gesture == GESTURE_TRIPLE_TAP:
        audio.play_fx("double_tap")
    if gesture == GESTURE_TRIPLE_TAP:
        go_back()
        return
    if current_state == STATE_FACE:
        _input_face(gesture)
    elif current_state == STATE_MENU:
        _input_menu(gesture)
    elif current_state == STATE_FLASHCARD:
        _input_flashcard(gesture)
    elif current_state == STATE_QUIZ:
        _input_quiz(gesture)
    elif current_state == STATE_NEURAL:
        _input_neural(gesture)
    elif current_state == STATE_GAMES:
        _input_games(gesture)
    elif current_state == STATE_SETTINGS:
        _input_settings(gesture)
    elif current_state == STATE_TALK:
        _input_talk(gesture)
    elif current_state == STATE_ANALYSE:
        _input_analyse(gesture)
def _input_face(gesture):
    if gesture == GESTURE_TAP:
        _transition_to_state(STATE_MENU)
    elif gesture == GESTURE_DOUBLE_TAP:
        _transition_to_state(STATE_MENU)
def _input_menu(gesture):
    if gesture == GESTURE_TAP:
        menu.navigate_down()
    elif gesture == GESTURE_DOUBLE_TAP:
        item = menu.select_current()
        if item:
            target_state = item.get("state", STATE_FACE)
            _transition_to_state(target_state)
def _input_flashcard(gesture):
    if flashcards is None:
        return
    if gesture == GESTURE_TAP:
        if flashcards.card_state == 0:
            flashcards.flip_card()
        else:
            flashcards.mark_correct()
            flashcards.save_progress(runtime_flashcards_path())
    elif gesture == GESTURE_DOUBLE_TAP:
        if flashcards.card_state == 0:
            flashcards.flip_card()
        elif flashcards.card_state == 1:
            flashcards.mark_wrong()
            flashcards.save_progress(runtime_flashcards_path())
def _input_quiz(gesture):
    if quiz is None:
        return
    if gesture == GESTURE_TAP:
        from quiz import QZ_SHOWING, QZ_COMPLETE
        if quiz.state == QZ_SHOWING:
            quiz.cycle_choice()
        elif quiz.state == QZ_COMPLETE:
            go_back()
    elif gesture == GESTURE_DOUBLE_TAP:
        from quiz import QZ_SHOWING
        if quiz.state == QZ_SHOWING:
            quiz.submit_answer()
def _input_neural(gesture):
    if neural is None:
        return
    if gesture == GESTURE_TAP:
        neural.select_next()
def _input_games(gesture):
    if games is None:
        return
    from games import GAME_SELECT
    if gesture == GESTURE_TAP:
        games.navigate()
    elif gesture == GESTURE_DOUBLE_TAP:
        games.select()
def _input_settings(gesture):
    if gesture == GESTURE_TAP:
        if wifi and not wifi.connected and not wifi.connecting:
            wifi.connect()
    elif gesture == GESTURE_DOUBLE_TAP:
        if wifi and not wifi.connected and not wifi.connecting:
            wifi.connect()
def _input_talk(gesture):
    if gesture == GESTURE_TAP:
        face.set_talk(not face._talk_active)
def _input_analyse(gesture):
    if gesture == GESTURE_TAP:
        _set_temp_expression(EXPR_THINK, 2000)
def render_frame():
    """Render the current state to the OLED."""
    if current_state == STATE_BOOT:
        boot_anim.render(oled)
    elif current_state == STATE_FACE:
        face.render(oled)
        status.render_minimal(oled)
        tof.render_overlay(oled, frame_count)
    elif current_state == STATE_MENU:
        menu.render(oled)
    elif current_state == STATE_FLASHCARD:
        if flashcards:
            flashcards.render(oled)
    elif current_state == STATE_QUIZ:
        if quiz:
            quiz.render(oled)
    elif current_state == STATE_NEURAL:
        if neural:
            neural.render(oled)
    elif current_state == STATE_GAMES:
        if games:
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

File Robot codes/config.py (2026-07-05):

I2C_SDA_PIN     = 15
I2C_SCL_PIN     = 14
I2C_FREQ        = 400_000
TOUCH_PIN       = 16
LED_PIN         = 18
BATTERY_ADC_PIN = 29
I2S_LRC_PIN     = 27
I2S_BCLK_PIN    = 26
I2S_DIN_PIN     = 28
AUDIO_VOLUME    = 0.30
MIC_I2S_ID        = 1
MIC_SCK_PIN       = 19
MIC_WS_PIN        = 20
MIC_SD_PIN        = 21
MIC_SAMPLE_RATE   = 16000
MIC_BITS          = 16
MIC_TRIGGER_LEVEL = 220
MIC_TRIGGER_HITS  = 3
MIC_GAIN          = 2
MIC_RECORD_MS     = 6000
MIC_MIN_RECORD_MS = 900
MIC_SILENCE_LEVEL = 1400
MIC_SILENCE_MS    = 450
MIC_COOLDOWN_MS   = 1600
VOICE_PUSH_TO_TALK = False
VOICE_SAVE_STUDY_PACKS = False
VOICE_DEBUG = False
AUDIO_DEBUG = False
MIC_DEMO_RECORD_MS = 4500
SD_SPI_ID       = 1
SD_SCK_PIN      = 10
SD_MOSI_PIN     = 11
SD_MISO_PIN     = 12
SD_CS_PIN       = 13
SD_BAUDRATE     = 1_000_000
SD_MOUNT_POINT  = "/sd"
SD_MOUNT_MARKER = ".aido_sd_mounted"
ENABLE_SD_CARD  = True
SD_REQUIRED     = False
FORCE_LOCAL_STORAGE = False
VOICE_LOCAL_AUDIO = False
VOICE_RECORD_LOCAL = False
VOICE_REPLY_LOCAL = False
SD_WELCOME_WAV  = "/sd/welcome.wav"
SD_VOICE_IN_WAV = "/sd/voice_in.wav"
SD_VOICE_REPLY_WAV = "/sd/voice_reply.wav"
OLED_WIDTH      = 128
OLED_HEIGHT     = 64
OLED_ADDR       = 0x3C
MPU_ADDR        = 0x68
STATE_BOOT      = 0
STATE_FACE      = 1
STATE_MENU      = 2
STATE_ACTION    = 3
STATE_FLASHCARD = 4
STATE_QUIZ      = 5
STATE_TALK      = 6
STATE_SETTINGS  = 7
STATE_NEURAL    = 8
STATE_GAMES     = 9
STATE_ANALYSE   = 10
TOUCH_MODE        = "auto"
TOUCH_ACTIVE_LOW  = False
DEBOUNCE_MS       = 18
DOUBLE_TAP_MS     = 340
TRIPLE_TAP_MS     = 260
TOUCH_AUTO_RELEASE_MS = 170
STATE_INPUT_LOCK_MS = 100
FRAME_DELAY_MS    = 33
BLINK_INTERVAL_MS = 3500
BLINK_DURATION_MS = 150
BLINK_RANDOM_MS   = 2000
EYE_SMOOTH_FACTOR = 0.15
MENU_SCROLL_SPEED = 4
BOOT_ANIM_MS      = 2500
LEFT_EYE_CX     = 38
LEFT_EYE_CY     = 30
RIGHT_EYE_CX    = 90
RIGHT_EYE_CY    = 30
EYE_WIDTH       = 24
EYE_HEIGHT      = 20
EYE_RADIUS      = 6
PUPIL_RADIUS    = 5
PUPIL_MAX_MOVE  = 6
IRIS_RADIUS     = 3
BROW_WIDTH      = 26
BROW_HEIGHT     = 3
BROW_Y_OFFSET   = -14
BROW_GAP        = 2
MOUTH_Y         = 48
MOUTH_WIDTH     = 30
MOUTH_CX        = 64
MPU_ACCEL_RANGE = 2
MPU_GYRO_RANGE  = 250
MPU_TILT_SCALE  = 0.00006103
MPU_EYE_GAIN    = 8.0
BATT_FULL_V     = 4.2
BATT_EMPTY_V    = 3.3
BATT_DIVIDER    = 3.0
ADC_VREF        = 3.3
ADC_MAX         = 65535
WIFI_SSID       = "Arm"
WIFI_PASS       = "ARM%ASL1220code"
WIFI_TIMEOUT_S  = 10
TTS_SERVER_HOST = "aido-voice.vercel.app"
TTS_SERVER_PATH = "/api/voice"
REFRESH_WELCOME_WAV = True
PLAY_WELCOME_VOICE = True
AUTO_REFRESH_INVALID_WAV = False
WELCOME_TEXT    = "Hello, I'm Aido. I'm ready for questions."
MENU_ITEMS = [
    {"label": "Analyse",    "state": STATE_ANALYSE,   "icon": "analyse"},
    {"label": "Flashcards", "state": STATE_FLASHCARD,  "icon": "cards"},
    {"label": "Quiz",       "state": STATE_QUIZ,       "icon": "quiz"},
    {"label": "Neural Map", "state": STATE_NEURAL,     "icon": "neural"},
    {"label": "Games",      "state": STATE_GAMES,      "icon": "games"},
    {"label": "Settings",   "state": STATE_SETTINGS,   "icon": "settings"},
]
EXPR_NEUTRAL  = 0
EXPR_HAPPY    = 1
EXPR_SAD      = 2
EXPR_ANGRY    = 3
EXPR_SURPRISE = 4
EXPR_SLEEPY   = 5
EXPR_LOVE     = 6
EXPR_THINK    = 7
EXPR_BLINK    = 8
EXPR_WINK     = 9
EXPR_TALK     = 10
MAX_CARDS       = 50
QUIZ_TIME_S     = 30
SR_INTERVALS    = [1, 3, 7, 14, 30]

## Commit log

2026-07-05 Adding .pptx powerpoint presentation
2026-07-05 Supabase .csv important files
    [sessions_rows.csv, subscriptions_rows.csv, usage_logs_rows.csv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]
